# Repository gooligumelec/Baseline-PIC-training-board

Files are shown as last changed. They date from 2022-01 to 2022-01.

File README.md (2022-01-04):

# Gooligum Baseline PIC Training and Development Board

The Gooligum Baseline and Mid-Range PIC training board, previously available for sale from www.gooligum.com.au, was designed for use with the Gooligum PIC tutorials, which you can find at https://github.com/gooligumelec/PIC-tutorials.  It is also useful as a general development board for 6-, 8- and 14-pin baseline, midrange and enhanced midrange PICs.

The design files are being made available under the Creative Commons Attribution-ShareAlike 4.0 International license, which essentially means that they are free to use and share, provided that you attribute the original creator (me / Gooligum). See LICENSE.txt for details.

The files consist of the manual, Eagle schematic and board files, bill of materials in Excel format and a zip file containing the Gerber and drill CAM files.

Please note that I am not in a position to provide any support for this board.

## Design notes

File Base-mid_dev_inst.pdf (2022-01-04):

© Gooligum Electronics 2015 | www.gooligum.com.au
Baseline and mid-range PIC training and dev board operation guide | Page 1

## Baseline and Mid-Range PIC (6 – 14 pin)

## Training and Development Board

## Construction and Operation Guide

This PIC development board is designed as a training environment specifically for use with the introductory Gooligum baseline, mid-range and enhanced mid-range PIC tutorials¹

The tutorials were originally written for Microchip’s Low Pin Count Demo Board, which supports 8-, 14-and 20-pin PICs, can be used easily with a PICkit 2 or PICkit 3 programmer, and provides four LEDs, a pushbutton switch and a potentiometer. As such, it’s a good, simple introductory board. However, it does not support the 6-pin 10F PICs and its LEDs cannot be used directly with 8-pin PICs.

More significantly, many of the Gooligum baseline and mid-range lessons require the use of parts not included on that board, such as photocells, crystal-driven oscillator circuits, and 7-segment LED displays. Although it is possible to build all of these circuits on a breadboard, connected to the Low Pin Count Demo Board, it is a little cumbersome – especially for some of the more complex circuits.

This training board was developed to make it easy to follow the Gooligum baseline, mid-range and introductory enhanced mid-range lessons. It works with a PICkit 2 or PICkit 3 programmer, and supports all 8- and 14-pin baseline, mid-range and enhanced mid-range PICs, as well as all 6-pin 10F devices (in an 8-pin DIP package). It is fully configurable using the provided jumpers, and comes with all of the hardware needed for every introductory lesson, including all the required PICs.

It features:

- Support for all 6-pin, 8-pin and 14-pin baseline, mid-range and enhanced mid-range PICs (all 10F, 12F and 14-pin 16F devices)
- 2 × pushbuttons (including MCLR )
- optional external pull-up resistor on each pushbutton
- 9 × LEDs
- an LED is available on each 6-pin and 8-pin PIC output pin, plus pins RC0 – RC3
- 3 × 7-segment LED displays
- configurable as a single digit or multiplexed digits
- External 32.768 kHz oscillator
- can be configured to drive processor clock, Timer0 or Timer1
- 4 MHz resonator, 32.768 kHz crystal and resistor/capacitor for use with processor oscillator
- 32.768 kHz crystal also available for Timer1 oscillator
- Potentiometer and 2 × photocells for use as analog inputs in comparator and ADC lessons
- Variable frequency oscillator for frequency and pulse width measurement lessons
- Piezo sounder, to demonstrate PWM outputs
- Standard ICSP connector for use with PICkit 2 or PICkit 3 programmer

1 All baseline, mid-range, and introductory enhanced mid-range assembler and C lessons

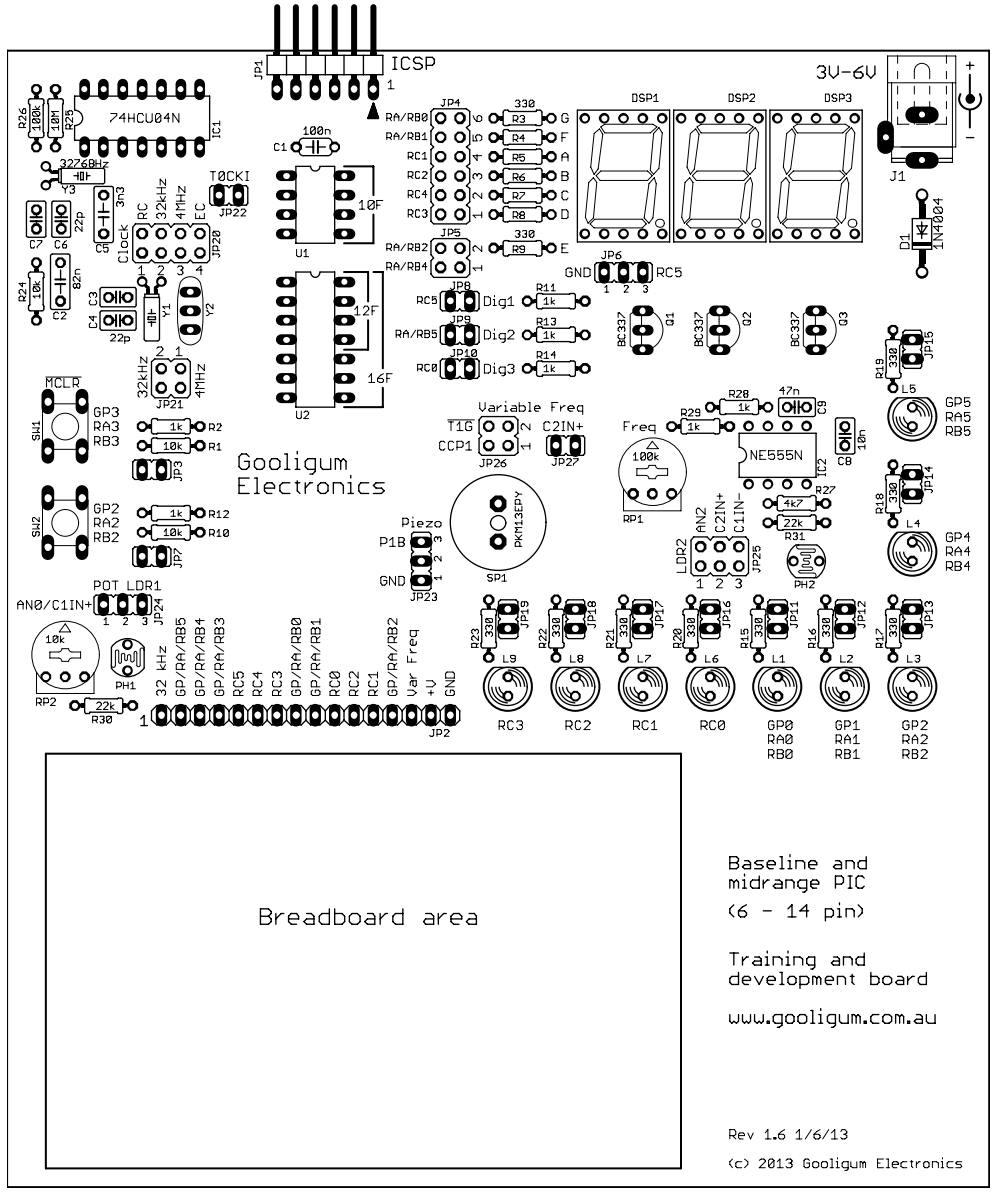
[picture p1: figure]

Baseline and mid-range PIC training and dev board operation guide | Page 2

Every PIC pin is brought out to the header at the bottom of the board, allowing the easy prototyping on the breadboard of circuits not covered by the onboard components, including circuits which require more than the 20 mA or so that a PICkit 2 or PICkit 3 can deliver, through the use of an external regulated DC power supply.

So, when you’ve completed all the lessons, you can continue to use the board for PIC development.

### Construction

[If your training board came fully assembled, you can ignore this section…]

The training board kit consists of a printed circuit board, a set of components to be soldered to the board, jumper shunts, rubber feet, a solderless breadboard, and solid hook-up wire (for use with the breadboard). It also comes with a bag of additional components for use with some of the Gooligum tutorial lessons – these are not to be mounted on the PCB. See the parts list, in appendix B, for details.

Construction is straight-forward, only needing basic soldering skills. All components are through-hole, and a component overlay (as shown below) is provided on the PCB.

Baseline and mid-range PIC training and dev board operation guide | Page 3

It is often easiest to build up a PCB by starting with the lowest-profile components, and working your way up in height – orienting them as shown in the overlay.

Be careful in particular with the orientation of the LEDs – although the anode lead is usually the longest, this is not always the case. It is safer to align the flat side of the case with the flat side of the overlay symbol (indicated the cathode).

The kit includes one green, one yellow and seven red LEDs. You can distribute these however you wish, but the colour scheme used in the prototype is green on GP0, yellow on GP1 and red on the rest.

The integrated circuits (74HCU04 and 555 timer) can be soldered directly to the PCB, in the positions marked IC1 and IC2 – taking care that the orientation is correct, with the notch on the IC (if any) aligned with the notch in the overlay symbol, and pin 1 (sometimes marked by a dot on the IC) immediately to the left of the notch. If you prefer to use IC sockets, that’s ok, but you will need to supply them yourself.

DO NOT use the supplied IC sockets for IC1 or IC2. These are to go in positions U1 and U2, to be used to mount the PICs that you will later use with this board.

Note that although the PCB overlay shows ‘BC337’, BC547 or BC548 transistors may have been supplied with your kit. That’s ok – they’ll all work fine in this application (driving the 7-segment displays) and have the same pin-out. Whichever type of transistor was supplied, you should orient them as shown on the overlay.

The 7-segment displays should be oriented with the decimal point in the lower right of each digit.

The jumper headers may have been supplied as a 32-pin single-row header, a 9-pin single-row header, and 19-position dual-row header. If so, they must be snapped (using pliers) into a number of smaller header blocks:

- 1 × 1×32-pin → 16 × 1×2-pin
- 1 × 1×9-pin → 3 × 1×3-pin
- 1 × 2×19-pin → 1 × 2×3-pin, 1 × 2×4-pin, 1 × 2×6-pin and 3 × 2×2-pin

Although the headers are a similar height to the LEDs, it is generally easiest to install them first, before installing the LEDs.

When you have soldered all the components to the PCB, peel the backing from the four rubber feet and attach them to the underside of the PCB, close to each corner.

You should also remove the paper backing from the solderless breadboard and attach it to the PCB, in the position shown in the overlay.

The supplied hook-up wire is used to make connections on the breadboard – you should put it aside and cut it into suitable lengths (with the insulation stripped from each end) as needed, later. Of course, if you already have a collection of breadboard jumper wires, feel free to use those instead!

The header shunts should also be put aside to use later, when you configure the training board for each lesson.

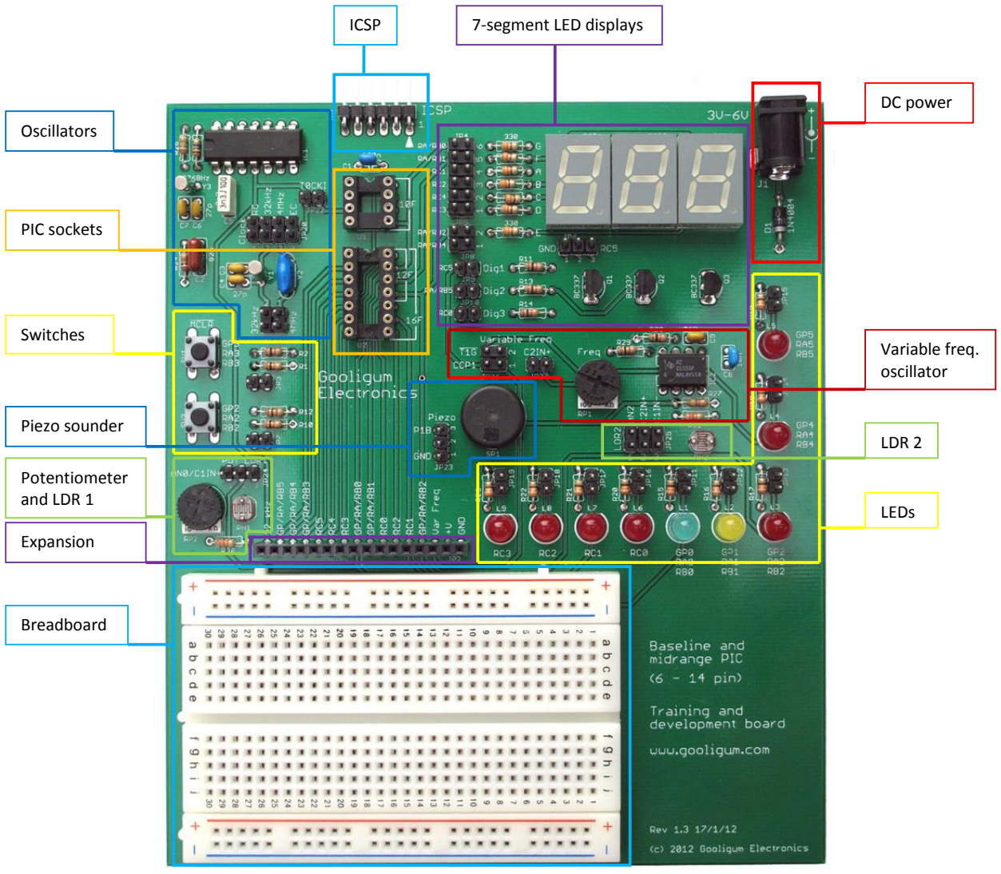
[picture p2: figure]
ICSP; Oscillators; Switches; Potentiometer and LDR 1; Breadboard; Expansion; Piezo sounder; 7-segment LED displays; DC power; PIC sockets; Variable freq. oscillator; LDR 2; LEDs

Baseline and mid-range PIC training and dev board operation guide | Page 4

### Operation

The training board consists of a number of functional blocks, as shown:

Plug your PIC microcontroller into one of the PIC sockets:
- Socket U1, marked ‘10F’, is for PIC10F devices²
- The upper section of socket U2, marked ‘12F’, is for 8-pin PIC12F devices
- The whole of socket U2, marked ‘16F’, is for 14-pin PIC16F devices

Note: you must plug a PIC into ONLY ONE socket at once. If you’ve been using a PIC10F and want to use a PIC12F or PIC16F, remove the PIC10F from the ‘10F’ socket first!

2 Although PIC10Fs are 6-pin devices, only those supplied in 8-pin DIP packages can be used (directly) with this training board. Only 6 pins of the 8-pin package are available for use; the PIC10F is still a 6-pin device.

Baseline and mid-range PIC training and dev board operation guide | Page 5

Plug your PICkit 2 or PICkit 3 programmer directly into the ICSP socket, with the arrow on the programmer aligned with the arrow on the PCB (indicating pin 1).

You would normally use the PICkit 2 or PICkit 3 to power the training board. These programmers can supply up to around 30 mA. If you need more current than this (up to 1 A), or if you wish to use the training board without having a PICkit 2 or PICkit 3 attached, you can connect a regulated power supply to the DC power socket.

This socket accepts a standard 5.5 mm barrel DC plug, with a 2.1 mm positive centre pin.

Note that there is no voltage regulator on the training board. A diode offers polarity protection, also dropping the supply voltage by at least 0.6 V. Since most baseline and mid-range PICs (including those used in the Gooligum tutorials) will work with a supply voltage of up to 5.5 V, you can safely use a power supply of up to 6 V to power most³
PICs with this training board – but it must be regulated!

A good choice for an external power supply is a 5 V regulated unit, which will supply around 4.3 V (after the diode voltage drop) to the PIC.

The LEDs are connected, via jumpers and 330 Ω resistors, to PIC pins as marked on the circuit board.

Various PICs use different names for the same pin. For example, pin 2 of socket U2 is referred to as GP5 if you plug a 12F509 into that socket, RA5 if you plug in a 16F684, and RB5 if you use a 16F506. For that reason, the LED connected to that pin is labelled ‘GP5 / RA5 / RB5’. On the other hand, pin 7 is called RC3 on all 14-pin PICs, so the LED on that pin is labelled simply ‘RC3’.

LEDs are available on all output pins except RC4 and RC5.

To enable (connect) an LED, simply close its associated jumper.

Pushbutton switches are connected to GP/RA/RB2 and GP/RA/RB3/ MCLR via 1 kΩ isolation resistors. They are active low: they will pull the input pin low when pressed (the isolation resistors ensure that the PIC won’t be damaged if a button is pressed while the pin connected to it is configured as a high output).

The inputs are normally held high, while the switch is open, by either an external 10 kΩ pull-up resistor, or an internal weak pull-up. Each external pull-up resistor is enabled by closing its associated jumper.

A 10 kΩ potentiometer and light-dependent resistor (LDR, or CDS photocell), forming one leg of a potential divider, are available as analog voltage sources. Either can be connected, via jumper JP24, to pin AN0 / CIN+ / C1IN+, to act as either an ADC or comparator input.

A second LDR can be connected, via jumper block JP25, to ADC input AN2 or comparator inputs C2IN+ or CIN- / C1IN-.

The board includes a 32.768 kHz oscillator, implemented with a watch crystal and CMOS inverter. Its buffered output can be used to drive Timer0 (in counter mode), by using JP22 to connect it to the T0CKI pin. It can also be used as an external signal to drive the processor clock, via jumper block JP20.

In a real PIC application, if you needed a 32.768 kHz clock, you’d be more likely to simply use a watch crystal with the PIC’s internal oscillator. The training board includes a second 32.768 kHz crystal (with load capacitors), which can be connected to OSC1 (on one side) via JP20 and to OSC2 (on the other

3
some PICs (mostly ‘LF’ variants) will only tolerate a supply of up to 3.6 V- you should limit your external power supply to no more than 4 V if you are using one of these devices

Baseline and mid-range PIC training and dev board operation guide | Page 6

side) via JP21. That is, to use the 32.768 kHz crystal with the PIC’s internal oscillator, you must connect it through both JP20 and JP21.

The same is true for the 4.00 MHz ceramic resonator. To use it with the PIC’s internal oscillator, connect one side of the resonator to OSC1 via JP20 and the other side to OSC2 via JP21.

A 10 kΩ resistor and 82 nF capacitor are also provided, and can be connected via JP20 to OSC1, to form an external RC oscillator with a frequency of around 1 kHz.

The 7-segment LED displays consist of three common-cathode digits, with the anodes of segments A-D, F and G connected via 330 Ω resistors and jumper block JP4 to pins RA/RB0-1 and RC1-4. Segment E can be connected via JP5 to either RA/RB2 or RA/RB4.

The common cathode of digit 1 (the digit on the left) can be connected either to ground or a transistor controlled by RC5, using jumper JP6.

The cathodes of digits 2 and 3 are connected to transistors controlled by RA/RB5 and RC0 respectively.

The base of each of these NPN transistors is connected to its associated PIC pin through a 1 kΩ resistor and a jumper: JP8 for digit 1, JP9 for digit 2, and JP10 for digit 3. When the PIC pin pulls the base high, the transistor conducts, shorting the common cathode of the attached digit to ground.

So, to use just a single digit:

- Connect segments A-D, F and G to their associated PIC pins, by placing a shunt across every position in jumper block JP4. That is, you use six shunts at once, in JP4.
- Connect segment E to either RA/RB2 or RA/RB4, by placing a shunt in one of the two positions in jumper block JP5, selecting the PIC pin to be used for segment E.
- Connect the common cathode of digit 1 to ground, by placing a shunt across pins 1 and 2 of jumper JP6.
- Leave jumpers JP8, JP9 and JP10 open, so that the transistors will not conduct.

To use multiple digits:

- Connect segments A-G to PIC pins using jumper blocks JP4 and JP5, as above.
- If you want to use digit 1, connect its common cathode to the transistor controlled by RC5, by placing a shunt across pins 2 and 3 of JP6.
- Connect the transistors controlling whichever digits you wish to use to their associated PIC pins, using jumpers JP8, JP9 and JP10

For a two-digit display, you would normally use digits 1 and 2, by connecting pins 2 and 3 of JP6, closing JP8 and JP9, and leaving JP10 open. The two digits would be activated by RC5 and RA/RB5.

But you could instead choose to use digits 2 and 3, by closing JP9 and JP10, and leaving JP6 and JP8 open. The two digits would then be activated by RA/RB5 and RC0.

For a three-digit display, connect pins 2 and 3 of JP6, and close JP8, JP9 and JP10. The three digits are activated by RC5, RA/RB5 and RC0.

Note that, if you are using multiple digits, you should ensure that only one transistor (and hence digit) is activated at once.

The variable frequency oscillator, based on a 555 timer, provides a signal with a frequency that can be varied from approximately 150 Hz to 10 kHz, using trimpot RP1.

The digital form of this signal can be connected to either the Timer 1 gate input, T1G , or the capture input pin, CCP1, using jumper block JP26.

Baseline and mid-range PIC training and dev board operation guide | Page 7

A sawtooth form of the variable frequency signal can be connected to comparator input C2IN+, via jumper JP27.

A piezo sounder is connected directly to pin RC5, which is also PWM output P1A.

To drive the piezo using a single-ended PWM output (or by toggling RC5), the other side of the piezo should be connected to ground, by placing a shunt across positions 1 and 2 of jumper JP23.

Alternatively, the piezo can be driven (at higher volume) by a double-ended or half-bridge PWM output, by placing a shunt across positions 2 and 3 of JP23, connecting its other side to PWM output P1B.

Finally, every PIC pin, the 32.768 kHz and variable frequency signals and the power supply are brought out to a 16-pin expansion header, next to the breadboard (making it easy to build custom circuits and to use this training board a general 6 – 14-pin PIC development board), as follows:

Pin | Description
1 | 32.768 kHz buffered digital signal
2 | GP5 / RA5 / RB5
3 | GP4 / RA4 / RB4
4 | GP3 / RA3 / RB3
5 | RC5
6 | RC4
7 | RC3
8 | GP0 / RA0 / RB0
9 | GP1 / RA1 / RB1
10 | RC0
11 | RC2
12 | RC1
13 | GP2 / RA2 / RB2
14 | Variable frequency (150 – 10000 Hz) digital signal
15 | Power (+V)
16 | Ground

Baseline and mid-range PIC training and dev board operation guide | Page 8

Jumper summary

As described above, jumpers are used to configure each function, bringing different elements in or out of the circuit. Although the function of each jumper is annotated on the PCB overlay, here is a summary of what each jumper is used for:

Jumper | Position | Function
JP3 | - | Enables external pull-up resistor on GP3 / RA3 / RB3 / MCLR
JP4 | 1 | Connects RC3 to LED digits segment D
| 2 | Connects RC4 to LED digits segment C
| 3 | Connects RC2 to LED digits segment B
| 4 | Connects RC1 to LED digits segment A
| 5 | Connects RA1 / RB1 to LED digits segment F
| 6 | Connects RA0 / RB0 to LED digits segment G
JP5 | 1 | Connects RA4 / RB4 to LED digits segment E
| 2 | Connects RA2 / RB2 to LED digits segment E
JP6 | 1-2 | Connects common cathode of LED digit 1 to ground
| 2-3 | Connects common cathode of LED digit 1 to transistor controlled by RC5
JP7 | - | Enables external pull-up resistor on GP2 / RA2 / RB2
JP8 | - | Connects RC5 to transistor on LED digit 1
JP9 | - | Connects RA5 / RB5 to transistor on LED digit 2
JP10 | - | Connects RC0 to transistor on LED digit 1
JP11 | | Connects GP0 / RA0 / RB0 to LED L1
JP12 | | Connects GP1 / RA1 / RB1 to LED L2
JP13 | | Connects GP2 / RA2 / RB2 to LED L3
JP14 | | Connects GP4 / RA4 / RB4 to LED L4
JP15 | | Connects GP5 / RA5 / RB5 to LED L5
JP16 | | Connects RC0 to LED L6
JP17 | | Connects RC1 to LED L7
JP18 | | Connects RC2 to LED L8
JP19 | | Connects RC3 to LED L9
JP20 | 1 | Connects OSC1 to 10 kΩ resistor and 82 nF capacitor (RC oscillator)
| 2 | Connects OSC1 to 32.768 kHz watch crystal (LP oscillator)
| 3 | Connects OSC1 to 4.00 MHz ceramic resonator (XT oscillator)
| 4 | Connects OSC1 to 32.768 kHz external clock (EC mode)
JP21 | 1 | Connects OSC2 to 4.00 MHz ceramic resonator (XT oscillator)
| 2 | Connects OSC2 to 32.768 kHz watch crystal (LP oscillator)

Baseline and mid-range PIC training and dev board operation guide | Page 9
JP22 | - | Connects T0CKI to 32.768 kHz external clock
JP23 | 1-2 | Connects one side of piezo sounder to ground (other side connects to P1A)
| 2-3 | Connects one side of piezo sounder to P1B (other side connects to P1A)
JP24 | 1-2 | Connects 10 kΩ potentiometer to RA0 / CIN+ / C1IN+
| 2-3 | Connects LDR1 to AN0 / CIN+ / C1IN+
JP25 | 1 | Connects LDR2 to AN2
| 2 | Connects LDR2 to C2IN+
| 3 | Connects LDR2 to CIN- / C1IN-
JP26 | 1 | Connects digital variable frequency signal to CCP1
| 2 | Connects digital variable frequency signal to T1G
JP27 | - | Connects sawtooth variable frequency signal to C2IN+

Baseline and mid-range PIC training and dev board operation guide | Page 10

### Appendix A – Jumper settings

The tables on the following pages show how the jumpers on the training board should be configured, for each baseline, mid-range or introductory enhanced mid-range tutorial example.

Use a shunt to connect jumpers indicated by ‘●’.

A single digit indicates that you should place a shunt at that numbered position in a jumper block.

‘1-2’ and ‘2-3’ mean that a shunt should be used to connect positions 1 and 2, or 2 and 3, of that jumper.

Jumper block JP4, used to connect PIC pins to six of the 7-segment display anodes, is all or nothing. Where you see ‘all’, you should place shunts across all six jumpers, numbered 1-6, in the block.

Where a table cell is blank, the jumper should be left open.

In many cases, it won’t matter if additional jumpers are connected, but to ensure that the board is correctly configured for each lesson, you should leave each jumper unconnected, unless specified.

For example, for mid-range assembler lesson 15, example 6, install shunts on:

- JP3 (enabling the pull-up resistor on the pushbutton on RA3)
- all positions (1-6) of JP4. connecting pins RA0-1 and RC1-4 to segments A-D and F-G of the 7-segment displays
- position 2 of JP5, connecting pin RA2 to segment E of the 7-segment displays
- pins 1 and 2 of JP6, connecting the common cathode of digit 1 to ground
- position 2 of JP20, connecting one side of a 32.768 kHz watch crystal to OSC1
- position 2 of JP21, connecting the other side of the watch crystal to OSC2

Every other jumper should remain open.

Baseline and mid-range PIC training and dev board operation guide | Page 11
Table A-1: Baseline assembler GP/RA³ pull-up | segment A⁻D,F,G | segment E | digit 1 cathode

GP/RA2 pull-up
RC5 → digit 1

RA5 → digit 2
RC0 → digit 3
GP/RA0 LED

GP/RA1 LED

GP/RA2 LED

GP/RA4 LED

GP/RA5 LED
RC0 LED

RC1 LED

RC2 LED

RC3 LED

Clock source

Crystal

32 kHz → T0CKI

Piezo

AN0 source

LDR2

Var Freq (digital)

Var Freq (analog)

Lesson | Example | 3 | 4 | 5 | 6 | 7 | 8 | 9 | 10 | 11 | 12 | 13 | 14 | 15 | 16 | 17 | 18 | 19 | 20 | 21 | 22 | 23 | 24 | 25 | 26 | 27
1 | 1 | | | | | | | | | | ●
2 | 1 | | | | | | | | | | ●
3 | 1 | | | | | | | | | | ●
| 2 | | | | | | | | | | ●
| 3 | | | | | | | | | | ●
4 | 1 | ● | | | | | | | | | ●
| 2 | ● | | | | | | | | | ●
| 3 | | | | | | | | | | ●
5 | 1 | ● | | | | | | | | | ● | ●
| 2 | ● | | | | | | | | | ● | ●
| 3 | ● | | | | | | | | | ●
| 4 | | | | | | | | | | ● | | | | | | | | | | ●
6 | 1 | | | | | | | | | | ●
| 2 | ● | | | | | | | | | ● | ●
| 3 | | | | | | | | | | ● | | | | | | | | | | ●
| 4 | ● | | | | | | | | | ●
| 5 | ● | | | | ● | | | | ● | ●
| 6 | | | | | | | | | | ●
7 | 1 | ● | | | | | | | | | ●
| 2 | ● | | | | | | | | | ● | ●
| 3 | | | | | | | | | | ● | ●
| 4a | | | | | | | | | | ● | | | | | | | | 4
| 4b | | | | | | | | | | ● | | | | | | | | 2 | 2
| 4c | | | | | | | | | | ● | | | | | | | | 3 | 1
| 4d | | | | | | | | | | ● | | | | | | | | 1
8 | 1 | | all | 1 | 1-2
| 2 | | all | 1 | 2-3 | | ● | ● | ●
| 3 | | all | 1 | 2-3 | | ● | ● | ●
9 | 1a | | | | | | | | | | | | | | | | | ● | | | | | 1-2
| 1b | | | | | | | | | | | | | | | | | ● | | | | | 2-3
| 1c | | | | | | | | | | | | | | | | | ● | | | | | 2-3
| 1d | | | | | | | | | | | | | | | | | ● | | | | | 2-3
| 2 | | | | | | | | | | | | | | | | | ● | | | | | 2-3
| 3 | | | | | | | | | | | | | | | | | ●
| 4 | | | | | | | | | | | | | | | ● | | ● | | | | | | 2
| 5 | | | | | | | | | | | | | | | ● | | ● | | | | | 2-3 | 2
10 | 1 | | | | | | | | | | | | | | ● | ● | ● | ● | | | | | 1-2
| 2 | | all | 1 | 2-3 | | ● | ● | | | | | | | | | | | | | | | | 1
| 3 | | all | 1 | 2-3 | | ● | ● | | | | | | | ●
11 | 1 | | all | 1 | 2-3 | | ● | ● | | | | | | | | | | | | | | | | 1
| 2 | | all | 1 | 2-3 | | ● | ● | | | | | | | | | | | | | | | | 1

Baseline and mid-range PIC training and dev board operation guide | Page 12

Table A-2: Baseline C

GP/RA3 pull-up

segment A-D,F,G

segment E

digit 1 cathode

GP/RA2 pull-up
RC5 → digit 1

RA5 → digit 2
RC0 → digit 3
GP/RA0 LED

GP/RA1 LED

GP/RA2 LED

GP/RA4 LED

GP/RA5 LED
RC0 LED

RC1 LED

RC2 LED

RC3 LED

Clock source

Crystal

32 kHz → T0CKI

Piezo

AN0 source

LDR2

Var Freq (digital)

Var Freq (analog)

Lesson | Example | 3 | 4 | 5 | 6 | 7 | 8 | 9 | 10 | 11 | 12 | 13 | 14 | 15 | 16 | 17 | 18 | 19 | 20 | 21 | 22 | 23 | 24 | 25 | 26 | 27
1 | 1 | | | | | | | | | | ●
| 2 | | | | | | | | | | ●
| 3 | | | | | | | | | | ●
2 | 1 | ● | | | | | | | | | ●
| 2 | ● | | | | | | | | | ●
| 3 | | | | | | | | | | ●
3 | 1 | ● | | | | | | | | | ● | ●
| 2 | ● | | | | | | | | | ● | ●
| 3 | ● | | | | | | | | | ●
| 4 | | | | | | | | | | ● | | | | | | | | | | ●
4 | 1 | ● | | | | | | | | | ●
| 2 | ● | | | | | | | | | ● | ●
| 3 | | | | | | | | | | ● | ●
5 | 1 | | all | 1 | 1-2
| 2 | | all | 1 | 2-3 | | ● | ● | ●
6 | 1a | | | | | | | | | | | | | | | | | ● | | | | | 1-2
| 1b | | | | | | | | | | | | | | | | | ● | | | | | 2-3
| 1c | | | | | | | | | | | | | | | | | ● | | | | | 2-3
| 1d | | | | | | | | | | | | | | | | | ● | | | | | 2-3
| 2 | | | | | | | | | | | | | | | | | ● | | | | | 2-3
| 3 | | | | | | | | | | | | | | | | | ●
| 4 | | | | | | | | | | | | | | | ● | | ● | | | | | | 2
| 5 | | | | | | | | | | | | | | | ● | | ● | | | | | 2-3 | 2
7 | 1 | | | | | | | | | | | | | | ● | ● | ● | ● | | | | | 1-2
| 2 | | all | 1 | 2-3 | | ● | ● | | | | | | | | | | | | | | | | 1
| 3 | | all | 1 | 2-3 | | ● | ● | | | | | | | ●
| 4 | | all | 1 | 2-3 | | ● | ● | | | | | | | | | | | | | | | | 1
| 5 | | all | 1 | 2-3 | | ● | ● | | | | | | | | | | | | | | | | 1

Baseline and mid-range PIC training and dev board operation guide | Page 13
Table A-3a: Mid-range assembler (lessons 1 - 8) GP/RA³ pull-up | segment A⁻D,F,G | segment E | digit 1 cathode | GP/RA² pull-up | RC5 → digit 1 | RA⁵ → digit 2 | RC0 → digit 3 | GP/RA⁰ LED | GP/RA¹ LED

GP/RA2 LED

GP/RA4 LED

GP/RA5 LED
RC0 LED

RC1 LED

RC2 LED

RC3 LED

Clock source

Crystal

32 kHz → T0CKI

Piezo

AN0 source

LDR2

Var Freq (digital)

Var Freq (analog)

Lesson | Example | 3 | 4 | 5 | 6 | 7 | 8 | 9 | 10 | 11 | 12 | 13 | 14 | 15 | 16 | 17 | 18 | 19 | 20 | 21 | 22 | 23 | 24 | 25 | 26 | 27
1 | 1 | ● | | | | | | | | | ●
| 2 | ● | | | | | | | | | ●
2 | 1 | ● | | | | | | | | | ●
| 2 | ● | | | | | | | | | ●
| 3 | ● | | | | | | | | | ●
3 | 1 | ● | | | | | | | | | ●
| 2 | ● | | | | | | | | | ●
| 3 | | | | | | | | | | ●
4 | 1 | ● | | | | | | | | | ● | ●
| 2 | ● | | | | | | | | | ● | ●
| 3 | ● | | | | | | | | | ●
| 4 | ● | | | | | | | | | ● | | | | | | | | | | ●
5 | 1 | ● | | | | | | | | | ●
| 2 | ● | | | | | | | | | ● | ●
| 3 | ● | | | | | | | | | ● | | | | | | | | | | ●
| 4 | ● | | | | | | | | | ●
| 5 | ● | | | | ● | | | | ● | ●
| 6 | ● | | | | | | | | | ●
6 | 1 | ● | | | | | | | | | | ●
| 2 | ● | | | | | | | | | ● | ●
| 3 | ● | | | | | | | | | ●
| 4 | ● | | | | | | | | | ● | ●
| 5 | ● | | | | ● | | | | | ●
| 6 | ● | | | | ● | | | | ● | ●
7 | 1 | ● | | | | ● | | | | | ●
| 2 | ● | | | | ● | | | | ● | ●
| 3 | ● | | | | | | | | | ●
| 4 | ● | | | | | | | | | ●
| 5 | ● | | | | | | | | | ● | ●
| 6 | ● | | | | | | | | | ●
8 | 1 | ●
| 2 | ● | | | | | | | | | ● | | | | | | | | 4
| 3 | ● | | | | | | | | | ● | | | | | | | | 2 | 2
| 4 | ● | | | | | | | | | ● | | | | | | | | 3 | 1
| 5 | ● | | | | | | | | | ● | | | | | | | | 1
| 6 | ● | | | | | | | | ● | ● | ●

Baseline and mid-range PIC training and dev board operation guide | Page 14
Table A-3b: Mid-range assembler (lessons 9 - 17) GP/RA³ pull-up | segment A⁻D,F,G | segment E | digit 1 cathode | GP/RA² pull-up | RC5 → digit 1 | RA⁵ → digit 2 | RC0 → digit 3

GP/RA0 LED

GP/RA1 LED

GP/RA2 LED

GP/RA4 LED

GP/RA5 LED
RC0 LED

RC1 LED

RC2 LED

RC3 LED

Clock source

Crystal

32 kHz → T0CKI

Piezo

AN0 source

LDR2

Var Freq (digital)

Var Freq (analog)

Lesson | Example | 3 | 4 | 5 | 6 | 7 | 8 | 9 | 10 | 11 | 12 | 13 | 14 | 15 | 16 | 17 | 18 | 19 | 20 | 21 | 22 | 23 | 24 | 25 | 26 | 27
9 | 1a | ● | | | | | | | | | | | | ● | | | | | | | | | 1-2
| 1b | ● | | | | | | | | | | | | ● | | | | | | | | | 2-3
| 2 | ● | | | | | | | | | | | | ● | | | | | | | | | 2-3
| 3 | ● | | | | | | | | | | | | ● | | | | | | | | | 2-3
| 4 | ● | | | | | | | | | | | | ● | | | | | | | | | 2-3
| 5 | ● | | | | | | | | | | | | ● | | | | | | | | | 2-3
| 6 | ● | | | | | | | | | | | ● | ● | | | | | | | | | 2-3
| 7 | ● | | | | | | | | | | | ● | ● | | | | | | | | | 2-3 | 3
10 | 1 | | | | | | | | | | | | | | ● | ● | ● | ●
| 2 | | | | | | | | | | | | | | ●
| 3 | | | | | | | | | | | | | | ●
11 | 1 | | | | | | | | | | | | ● | ● | | | ● | ● | | | | | 2-3 | 3
| 2 | | | | | | | | | | | | | | | | ● | ● | | | | | | 3
| 3 | | | | | | | | | | | | | | | | ● | ● | | | | | | 2
12 | 1 | | all | 1 | 1-2
| 2 | | all | 1 | 2-3 | | ● | ● | ●
| 3 | | all | 1 | 2-3 | | ● | ● | ●
13 | 1 | | | | | | | | | | | | | | ● | ● | ● | ● | | | | | 1-2
| 2 | | | | | | | | | | | | | | ● | ● | ● | ● | | | | | 1-2
| 3 | | all | 1 | 2-3 | | ● | ● | ● | | | | | | | | | | | | | | | 1
| 4 | | all | 1 | 2-3 | | ● | ● | ● | | | | | | | | | | | | | | | 1
| 5 | | all | 1 | 2-3 | | ● | ● | | | | | | | ●
14 | 1 | | all | 1 | 2-3 | | ● | ● | | | | | | | | | | | | | | | | 1
| 2 | | all | 1 | 2-3 | | ● | ● | | | | | | | | | | | | | | | | 1
15 | 1 | ● | | | | | | | | | | | | | ● | ●
| 2 | ● | | | | | | | | | | | | | ● | ●
| 3 | | | | | | | | | | | | | | ● | | | | 4
| 4 | | | | | | | | | | | | | | ● | | | | 2 | 2
| 5 | | all | 2 | 1-2 | | | | | | | | | | | | | | 2 | 2
| 6 | ● | all | 2 | 1-2 | | | | | | | | | | | | | | 2 | 2
| 7 | | all | 2 | 1-2 | | | | | | | | | | | | | | | | | | | | 2
| 8 | | all | 2 | 1-2 | | | | | | | | | | | | | | | | | | | | | ●
16 | 1 | | | | | | | | | | | | | | ●
17 | 1 | | all | 2 | 1-2 | | | | | | | | | | | | | | | | | | | | 1
| 2 | | all | 2 | 1-2 | | | | | | | | | | | | | | | | | | | | 1
| 3 | | all | 2 | 1-2 | | | | | | | | | | | | | | | | | | | | 1
| 4 | | | | | | | | | | | | | | | | | ●
| 5 | | | | | | | | | | | | | | | | | ●
| 6 | | | | | | | | | | | | | | | | | ●
| 7 | | all | 1 | 2-3 | | ● | ● | | | | | | | | | | | | | | | | 1

Baseline and mid-range PIC training and dev board operation guide | Page 15
Table A-3c: Mid-range assembler (lessons 18 - 19) GP/RA³ pull-up | segment A⁻D,F,G | segment E | digit 1 cathode | GP/RA² pull-up | RC5 → digit 1 | RA⁵ → digit 2 | RC0 → digit 3 | GP/RA⁰ LED | GP/RA¹ LED

GP/RA2 LED

GP/RA4 LED

GP/RA5 LED
RC0 LED

RC1 LED

RC2 LED

RC3 LED

Clock source

Crystal

32 kHz → T0CKI

Piezo

AN0 source

LDR2

Var Freq (digital)

Var Freq (analog)

Lesson | Example | 3 | 4 | 5 | 6 | 7 | 8 | 9 | 10 | 11 | 12 | 13 | 14 | 15 | 16 | 17 | 18 | 19 | 20 | 21 | 22 | 23 | 24 | 25 | 26 | 27
18 | 1
| 2 | | | | | | | | | | | | | | | | | | | | | 1-2 | 1-2
| 3 | | | | | | | | | | | | | | | | | ● | | | | | 1-2
| 4 | | | | | | | | | | | | | | | | | | | | | | 1-2
| 5 | | | | | | | | | | | | | | | | | | | | | 2-3
| 6 | | | | | | | | | | | | | | | | | | | | | | 1-2
| 7 | | | | | | | | | | | | | | | | | | | | | | 1-2
| 8 | | | | | | | | | | | | | | | | | | | | | | 1-2
19 | 1 | | all | 1 | 2-3 | | ● | ● | ●
| 2 | | all | 1 | 2-3 | | ● | ● | ●

Baseline and mid-range PIC training and dev board operation guide | Page 16
Table A-4a: Mid-range C (lessons 1 - 6) GP/RA³ pull-up | segment A⁻D,F,G | segment E | digit 1 cathode | GP/RA² pull-up | RC5 → digit 1 | RA⁵ → digit 2

RC0 → digit 3
GP/RA0 LED

GP/RA1 LED

GP/RA2 LED

GP/RA4 LED

GP/RA5 LED
RC0 LED

RC1 LED

RC2 LED

RC3 LED

Clock source

Crystal

32 kHz → T0CKI

Piezo

AN0 source

LDR2

Var Freq (digital)

Var Freq (analog)

Lesson | Example | 3 | 4 | 5 | 6 | 7 | 8 | 9 | 10 | 11 | 12 | 13 | 14 | 15 | 16 | 17 | 18 | 19 | 20 | 21 | 22 | 23 | 24 | 25 | 26 | 27
1 | 1 | ● | | | | | | | | | ●
| 2 | ● | | | | | | | | | ●
| 3 | ● | | | | | | | | | ●
| 4 | ● | | | | | | | | | ●
| 5 | ● | | | | | | | | | ●
| 6 | | | | | | | | | | ●
2 | 1 | ● | | | | | | | | | ● | ●
| 2 | ● | | | | | | | | | ● | ●
| 3 | ● | | | | | | | | | ●
| 4 | ● | | | | | | | | | ● | | | | | | | | | | ●
3 | 1 | ● | | | | | | | | | | ●
| 2 | ● | | | | | | | | | ● | ●
| 3 | ● | | | | | | | | | ●
| 4 | ● | | | | | | | | | ● | ●
| 5 | ● | | | | ● | | | | | ●
| 6 | ● | | | | ● | | | | ● | ●
4 | 1 | ● | | | | ● | | | | | ●
| 2 | ● | | | | ● | | | | ● | ●
| 3 | ● | | | | | | | | | ●
| 4 | ● | | | | | | | | | ●
| 5 | ● | | | | | | | | | ● | ●
| 6 | ● | | | | | | | | | ●
5 | 1 | ●
| 2 | ● | | | | | | | | | ● | | | | | | | | 4
| 3 | ● | | | | | | | | | ● | | | | | | | | 2 | 2
| 4 | ● | | | | | | | | | ● | | | | | | | | 3 | 1
| 5 | ● | | | | | | | | | ● | | | | | | | | 1
| 6 | ● | | | | | | | | ● | ● | ●
6 | 1 | ● | | | | | | | | | | | | ● | | | | | | | | | 2-3
| 2 | ● | | | | | | | | | | | | ● | | | | | | | | | 2-3
| 3 | ● | | | | | | | | | | | | ● | | | | | | | | | 2-3
| 4 | ● | | | | | | | | | | | | ● | | | | | | | | | 2-3
| 5 | ● | | | | | | | | | | | | ● | | | | | | | | | 2-3
| 6 | ● | | | | | | | | | | | ● | ● | | | | | | | | | 2-3
| 7 | ● | | | | | | | | | | | ● | ● | | | | | | | | | 2-3 | 3
| 8 | | | | | | | | | | | | ● | ● | | | ● | ● | | | | | 2-3 | 3
| 9 | | | | | | | | | | | | | | | | ● | ● | | | | | | 3
| 10 | | | | | | | | | | | | | | | | ● | ● | | | | | | 2

Baseline and mid-range PIC training and dev board operation guide | Page 17
Table A-4b: Mid-range C (lessons 7 - 13) GP/RA³ pull-up | segment A⁻D,F,G | segment E | digit 1 cathode | GP/RA² pull-up | RC5 → digit 1 | RA⁵ → digit 2 | RC0 → digit 3

GP/RA0 LED

GP/RA1 LED

GP/RA2 LED

GP/RA4 LED
GP/RA5 LED
RC0 LED

RC1 LED

RC2 LED

RC3 LED

Clock source

Crystal

32 kHz → T0CKI

Piezo

AN0 source

LDR2

Var Freq (digital)

Var Freq (analog)

Lesson | Example | 3 | 4 | 5 | 6 | 7 | 8 | 9 | 10 | 11 | 12 | 13 | 14 | 15 | 16 | 17 | 18 | 19 | 20 | 21 | 22 | 23 | 24 | 25 | 26 | 27
7 | 1 | | all | 1 | 1-2
| 2 | | all | 1 | 2-3 | | ● | ● | ●
8 | 1 | | | | | | | | | | | | | | ● | ● | ● | ● | | | | | 1-2
| 2 | | | | | | | | | | | | | | ● | ● | ● | ● | | | | | 1-2
| 3 | | all | 1 | 2-3 | | ● | ● | ● | | | | | | | | | | | | | | | 1
| 4 | | all | 1 | 2-3 | | ● | ● | ● | | | | | | | | | | | | | | | 1
| 5 | | all | 1 | 2-3 | | ● | ● | | | | | | | ●
| 6 | | all | 1 | 2-3 | | ● | ● | | | | | | | | | | | | | | | | 1
| 7 | | all | 1 | 2-3 | | ● | ● | | | | | | | | | | | | | | | | 1
9 | 1 | ● | | | | | | | | | | | | | ● | ●
| 2 | ● | | | | | | | | | | | | | ● | ●
| 3 | | | | | | | | | | | | | | ● | | | | 2 | 2
| 4 | | all | 2 | 1-2 | | | | | | | | | | | | | | 2 | 2
| 5 | ● | all | 2 | 1-2 | | | | | | | | | | | | | | 2 | 2
| 6 | | all | 2 | 1-2 | | | | | | | | | | | | | | | | | | | | 2
| 7 | | all | 2 | 1-2 | | | | | | | | | | | | | | | | | | | | | ●
10 | 1 | | | | | | | | | | | | | | ●
11 | 1 | | all | 2 | 1-2 | | | | | | | | | | | | | | | | | | | | 1
| 2 | | all | 2 | 1-2 | | | | | | | | | | | | | | | | | | | | 1
| 3 | | all | 2 | 1-2 | | | | | | | | | | | | | | | | | | | | 1
| 4 | | | | | | | | | | | | | | | | | ●
| 5 | | | | | | | | | | | | | | | | | ●
| 6 | | | | | | | | | | | | | | | | | ●
| 7 | | all | 1 | 2-3 | | ● | ● | | | | | | | | | | | | | | | | 1
12 | 1
| 2 | | | | | | | | | | | | | | | | | | | | | 1-2 | 1-2
| 3 | | | | | | | | | | | | | | | | | ● | | | | | 1-2
| 4 | | | | | | | | | | | | | | | | | | | | | | 1-2
| 5 | | | | | | | | | | | | | | | | | | | | | 2-3
| 6 | | | | | | | | | | | | | | | | | | | | | | 1-2
| 7 | | | | | | | | | | | | | | | | | | | | | | 1-2
| 8 | | | | | | | | | | | | | | | | | | | | | | 1-2
13 | 1 | | all | 1 | 2-3 | | ● | ● | ●
| 2 | | all | 1 | 2-3 | | ● | ● | ●
| 3 | | all | 1 | 2-3 | | ● | ● | ●

Baseline and mid-range PIC training and dev board operation guide | Page 18
Table A-5: Migrating to enhanced mid-range assembler GP/RA³ pull-up | segment A⁻D,F,G | segment E | digit 1 cathode | GP/RA² pull-up | RC5 → digit 1 | RA⁵ → digit 2 | RC0 → digit 3 | GP/RA⁰ LED | GP/RA¹ LED | GP/RA² LED | GP/RA⁴ LED

GP/RA5 LED
RC0 LED

RC1 LED

RC2 LED

RC3 LED

Clock source

Crystal

32 kHz → T0CKI

Piezo

AN0 source

LDR2

Var Freq (digital)

Var Freq (analog)

Lesson | Example | 3 | 4 | 5 | 6 | 7 | 8 | 9 | 10 | 11 | 12 | 13 | 14 | 15 | 16 | 17 | 18 | 19 | 20 | 21 | 22 | 23 | 24 | 25 | 26 | 27
1 | 1 | ● | | | | | | | | | ●
| 2 | ● | | | | | | | | | ●
| 3 | ● | | | | | | | | | ●
| 4 | ● | | | | | | | | | ●
| 5 | ● | | | | | | | | | ●
| 6 | | | | | | | | | | ●
2 | 1 | ● | | | | | | | | ● | ●
| 2 | | | | | | | | | | ● | | | | | | | | | | ●
| 3 | ● | | | | | | | | ● | ●
| 4 | | | | | ● | | | | | ●
3 | 1 | | | | | ● | | | | | ●
| 2 | | | | | ● | | | | ● | ●
| 3 | ● | | | | | | | | | ●
| 4 | ● | | | | | | | | | ●
| 5 | | | | | | | | | ● | ●
| 6 | | | | | | | | | | ●
4 | 1 | ● | | | | | | | | | | | | | | | ●
| 2 | | | | | | | | | | | | | | | | ● | | 3 | 1
| 3 | | | | | | | | | | | | | | | | ● | | 1
| 4 | | | | | | | | | | | | ● | | | | | | 1
| 5 | ● | | | | | | | | ● | ● | ●
5 | 1a | | | | | | | | | | | ● | | | | | | | | | | | 1-2
| 1b | | | | | | | | | | | ● | | | | | | | | | | | 1-2
| 1c | | | | | | | | | | | ● | | | | | | | | | | | 2-3
| 1d | | | | | | | | | | | ● | | | | | | | | | | | 2-3
| 2 | | | | | | | | | | | | | | | ● | | | | | | | | 3
| 3 | | | | | | | | | | | | | | | ● | | | | | | | | 3
| 4 | | | | | | | | | | | | | | | ● | | | | | | | | 3
| 5 | | | | | | | | | | | | | | | ● | | | | | | | | 3
| 6
| 7 | | | | | | | | | | | | | | | ● | | ● | | | | | | 3
6 | 1 | | all | 1 | 1-2
7 | 1 | | | | | | | | | | | | | | ● | ● | ● | ● | | | | | 1-2
| 2 | | all | 1 | 2-3 | | ● | ● | | | | ●
8 | 1 | | all | 1 | 2-3 | | ● | ● | | | | | | | | | | | | | | | | 1
| 2 | | all | 1 | 2-3 | | ● | ● | | | | | | | | | | | | | | | | 1
9 | 1 | | all | 2 | 1-2 | | | | | | | | | | | | | | | | | | | | 2
| 2 | | all | 2 | 1-2 | | | | | | | | | | | | | | | | | | | | 2
| 3 | | all | 2 | 1-2
10 | 1 | | | | | | | | | | | | | | ●
11 | 1 | | | | | | | | | | | | | | | | | ●
| 2 | | | | | | | | | | | | | | | ● | | | | | | | 1-2
| 3 | | | | | | | | | | | | | | | | | | | | | 2-3

Baseline and mid-range PIC training and dev board operation guide | Page 19
Table A-6: Migrating to enhanced mid-range C GP/RA³ pull-up | segment A⁻D,F,G | segment E | digit 1 cathode | GP/RA² pull-up | RC5 → digit 1 | RA⁵ → digit 2 | RC0 → digit 3 | GP/RA⁰ LED

GP/RA1 LED

GP/RA2 LED

GP/RA4 LED

GP/RA5 LED
RC0 LED

RC1 LED

RC2 LED

RC3 LED

Clock source

Crystal

32 kHz → T0CKI

Piezo

AN0 source

LDR2

Var Freq (digital)

Var Freq (analog)

Lesson | Example | 3 | 4 | 5 | 6 | 7 | 8 | 9 | 10 | 11 | 12 | 13 | 14 | 15 | 16 | 17 | 18 | 19 | 20 | 21 | 22 | 23 | 24 | 25 | 26 | 27
1 | 1 | ● | | | | | | | | | ●
| 2 | ● | | | | | | | | | ●
| 3 | ● | | | | | | | | | ●
| 4 | | | | | | | | | | ●
2 | 1 | ● | | | | | | | | ● | ●
| 2 | | | | | | | | | | ● | | | | | | | | | | ●
| 3 | ● | | | | | | | | ● | ●
| 4 | | | | | ● | | | | | ●
3 | 1 | | | | | ● | | | | | ●
| 2 | | | | | ● | | | | ● | ●
| 3 | ● | | | | | | | | | ●
| 4 | ● | | | | | | | | | ●
| 5 | | | | | | | | | ● | ●
| 6 | | | | | | | | | | ●
4 | 1 | ● | | | | | | | | | | | | | | | ●
| 2 | | | | | | | | | | | | | | | | ● | | 3 | 1
| 3 | | | | | | | | | | | | | | | | ● | | 1
| 4 | | | | | | | | | | | | ● | | | | | | 1
| 5 | ● | | | | | | | | ● | ● | ●
5 | 1a | | | | | | | | | | | ● | | | | | | | | | | | 1-2
| 1b | | | | | | | | | | | ● | | | | | | | | | | | 1-2
| 1c | | | | | | | | | | | ● | | | | | | | | | | | 2-3
| 1d | | | | | | | | | | | ● | | | | | | | | | | | 2-3
| 2 | | | | | | | | | | | | | | | ● | | | | | | | | 3
| 3 | | | | | | | | | | | | | | | ● | | | | | | | | 3
| 4 | | | | | | | | | | | | | | | ● | | | | | | | | 3
| 5 | | | | | | | | | | | | | | | ● | | | | | | | | 3
| 6
| 7 | | | | | | | | | | | | | | | ● | | ● | | | | | | 3
6 | 1 | | | | | | | | | | | | | | ● | ● | ● | ● | | | | | 1-2
| 2 | | all | 1 | 2-3 | | ● | ● | | | | ●
| 3 | | all | 1 | 2-3 | | ● | ● | | | | | | | | | | | | | | | | 1
7 | 1 | | all | 2 | 1-2 | | | | | | | | | | | | | | | | | | | | 2
| 2 | | all | 2 | 1-2 | | | | | | | | | | | | | | | | | | | | 2
| 3 | | all | 2 | 1-2
8 | 1 | | | | | | | | | | | | | | ●
9 | 1 | | | | | | | | | | | | | | | | | ●
| 2 | | | | | | | | | | | | | | | ● | | | | | | | 1-2
| 3 | | | | | | | | | | | | | | | | | | | | | 2-3

Baseline and mid-range PIC training and dev board operation guide | Page 20
Table A-7a: Enhanced mid-range assembler (lessons 1 - 10) GP/RA³ pull-up | segment A⁻D,F,G | segment E | digit 1 cathode | GP/RA² pull-up | RC5 → digit 1 | RA⁵ → digit 2 | RC0 → digit 3 | GP/RA⁰ LED | GP/RA¹ LED | GP/RA² LED | GP/RA⁴ LED | GP/RA⁵ LED

RC0 LED

RC1 LED

RC2 LED

RC3 LED

Clock source

Crystal

32 kHz → T0CKI

Piezo

AN0 source

LDR2

Var Freq (digital)

Var Freq (analog)

Lesson | Example | 3 | 4 | 5 | 6 | 7 | 8 | 9 | 10 | 11 | 12 | 13 | 14 | 15 | 16 | 17 | 18 | 19 | 20 | 21 | 22 | 23 | 24 | 25 | 26 | 27
1 | 1 | | | | | | | | | | ●
2 | 1 | | | | | | | | | | ●
3 | 1 | | | | | | | | | | ●
| 2 | | | | | | | | | | ●
4 | 1 | ● | | | | | | | | | ●
| 2 | ● | | | | | | | | | ●
| 3 | | | | | | | | | | ●
5 | 1 | ● | | | | | | | | ● | ●
| 2 | ● | | | | | | | | ● | ●
| 3 | ● | | | | | | | | | ●
| 4 | | | | | | | | | | ● | | | | | | | | | | ●
6 | 1 | | | | | | | | | | ●
| 2 | ● | | | | | | | | ● | ●
| 3 | | | | | | | | | | ● | | | | | | | | | | ●
| 4 | ● | | | | | | | | | ●
| 5 | ● | | | | ● | | | | ● | ●
| 6 | | | | | | | | | | ●
| 7a | ● | | | | | | | | | ●
| 7b | | | | | | | | | | ●
7 | 1 | | | | | | | | | ●
| 2 | ● | | | | | | | | ● | ●
| 3 | ● | | | | | | | | | ●
| 4 | ● | | | | | | | | ● | ●
| 5 | | | | | ● | | | | | ●
| 6 | | | | | ● | | | | ● | ●
8 | 1 | | | | | ● | | | | | ●
| 2 | | | | | ● | | | | ● | ●
| 3 | ● | | | | | | | | | ●
| 4 | ● | | | | | | | | | ●
| 5 | | | | | | | | | ● | ●
| 6 | | | | | | | | | | ●
9 | 1 | ● | | | | | | | | | | | | | | | ●
| 2 | | | | | | | | | | | | | | | | ● | | 4
| 3 | | | | | | | | | | | | | | | | ● | | 2 | 2
| 4 | | | | | | | | | | | | | | | | ● | | 3 | 1
| 5 | | | | | | | | | | | | | | | | ● | | 1
| 6 | | | | | | | | | | | | ● | | | | | | 1
| 7 | ● | | | | | | | | ● | ● | ●
10 | 1a | | | | | | | | | | | ● | | | | | | | | | | | 1-2
| 1b | | | | | | | | | | | ● | | | | | | | | | | | 1-2
| 1c | | | | | | | | | | | ● | | | | | | | | | | | 2-3
| 1d | | | | | | | | | | | ● | | | | | | | | | | | 2-3
| 2 | | | | | | | | | | | | | | | ● | | | | | | | | 3
| 3 | | | | | | | | | | | | | | | ● | | | | | | | | 3
| 4 | | | | | | | | | | | | | | | ● | | | | | | | | 3

Baseline and mid-range PIC training and dev board operation guide | Page 21
Table A-7b: Enhanced mid-range assembler (lessons 11 - 18) GP/RA³ pull-up | segment A⁻D,F,G | segment E | digit 1 cathode | GP/RA² pull-up | RC5 → digit 1 | RA⁵ → digit 2 | RC0 → digit 3 | GP/RA⁰ LED | GP/RA¹ LED | GP/RA² LED | GP/RA⁴ LED | GP/RA⁵ LED

RC0 LED

RC1 LED

RC2 LED

RC3 LED

Clock source

Crystal

32 kHz → T0CKI

Piezo

AN0 source

LDR2

Var Freq (digital)

Var Freq (analog)

Lesson | Example | 3 | 4 | 5 | 6 | 7 | 8 | 9 | 10 | 11 | 12 | 13 | 14 | 15 | 16 | 17 | 18 | 19 | 20 | 21 | 22 | 23 | 24 | 25 | 26 | 27
11 | 1 | | | | | | | | | | | | | | | ● | | | | | | | | 3
| 2
| 3 | | | | | | | | | | | | | | | ● | | ● | | | | | | 3
| 4 | | | | | | | | | | | | | | | ● | | ● | | | | | | 3
12 | 1 | | all | 1 | 1-2
| 2 | | all | 1 | 2-3 | | ● | ● | ●
| 3 | | all | 1 | 2-3 | | ● | ● | ●
13 | 1 | | | | | | | | | | | | | | ● | ● | ● | ● | | | | | 1-2
| 2 | | | | | | | | | | | | | | ● | ● | ● | ● | | | | | 1-2
| 3 | | all | 1 | 2-3 | | ● | ● | ● | | | | | | | | | | | | | | | 1
| 4 | | all | 1 | 2-3 | | ● | ● | ● | | | | | | | | | | | | | | | 1
| 5 | | all | 1 | 2-3 | | ● | ● | | | | ●
14 | 1 | | all | 1 | 2-3 | | ● | ● | | | | | | | | | | | | | | | | 1
| 2 | | all | 1 | 2-3 | | ● | ● | | | | | | | | | | | | | | | | 1
| 3 | | all | 1 | 2-3 | | ● | ● | | | | | | | | | | | | | | | | 1
15 | 1 | ● | | | | | | | | ● | ●
| 2 | ● | | | | | | | | ● | ●
| 3 | | | | | | | | | | ● | | | | | | | | 4
| 4 | | | | | | | | | | ● | | | | | | | | 2 | 2
| 5 | ● | all | 2 | 1-2 | | | | | | | | | | | | | | 2 | 2
| 6 | ● | all | 2 | 1-2 | | | | | | | | | | | | | | 2 | 2
| 7 | | all | 2 | 1-2 | | | | | | | | | | | | | | | | | | | | 2
| 8 | | all | 2 | 1-2 | | | | | | | | | | | | | | | | | | | | 2
| 9 | | all | 2 | 1-2
16 | 1 | | | | | | | | | | | | | | ●
17 | 1 | | all | 2 | 1-2 | | | | | | | | | | | | | | | | | | | | 1
| 2 | | all | 2 | 1-2 | | | | | | | | | | | | | | | | | | | | 1
| 3 | | all | 2 | 1-2 | | | | | | | | | | | | | | | | | | | | 1
| 4 | | | | | | | | | | | | | | | | | ●
| 5 | | | | | | | | | | | | | | ●
| 6 | | | | | | | | | | | | | | ●
| 7 | | all | 1 | 2-3 | | ● | ● | | | | | | | | | | | | | | | | 1
18 | 1
| 2 | | | | | | | | | | | | | | | ● | | | | | | | 1-2
| 3 | | | | | | | | | | | | | | | | | | | | | | 1-2
| 4 | | | | | | | | | | | | | | | | | | | | | 1-2 | 1-2
| 5 | | | | | | | | | | | | | | | | | | | | | 2-3
| 6 | | | | | | | | | | | | | | | | | | | | | | 1-2
| 7 | | | | | | | | | | | | | | | | | | | | | | 1-2
| 8 | | | | | | | | | | | | | | | | | | | | | | 1-2
| 9 | | | | | | | | | | | | | | | | | | | | | 2-3

Baseline and mid-range PIC training and dev board operation guide | Page 22
Table A-8a: Enhanced mid-range C (lessons 1 - 10) GP/RA³ pull-up | segment A⁻D,F,G | segment E | digit 1 cathode | GP/RA² pull-up | RC5 → digit 1 | RA⁵ → digit 2 | RC0 → digit 3 | GP/RA⁰ LED | GP/RA¹ LED

GP/RA2 LED

GP/RA4 LED

GP/RA5 LED
RC0 LED

RC1 LED

RC2 LED

RC3 LED

Clock source

Crystal

32 kHz → T0CKI

Piezo

AN0 source

LDR2

Var Freq (digital)

Var Freq (analog)

Lesson | Example | 3 | 4 | 5 | 6 | 7 | 8 | 9 | 10 | 11 | 12 | 13 | 14 | 15 | 16 | 17 | 18 | 19 | 20 | 21 | 22 | 23 | 24 | 25 | 26 | 27
1 | 1 | | | | | | | | | | ●
2 | 1 | | | | | | | | | | ●
3 | 1 | ● | | | | | | | | | ●
| 2 | ● | | | | | | | | | ●
| 3 | | | | | | | | | | ●
4 | 1 | ● | | | | | | | | ● | ●
| 2 | ● | | | | | | | | ● | ●
| 3 | ● | | | | | | | | | ●
| 4 | | | | | | | | | | ● | | | | | | | | | | ●
5 | 1 | | | | | | | | | ●
| 2 | ● | | | | | | | | ● | ●
| 3 | ● | | | | | | | | | ●
| 4 | ● | | | | | | | | ● | ●
| 5 | | | | | ● | | | | | ●
| 6 | | | | | ● | | | | ● | ●
6 | 1 | | | | | ● | | | | | ●
| 2 | | | | | ● | | | | ● | ●
| 3 | ● | | | | | | | | | ●
| 4 | ● | | | | | | | | | ●
| 5 | | | | | | | | | ● | ●
| 6 | | | | | | | | | | ●
7 | 1 | ● | | | | | | | | | | | | | | | ●
| 2 | | | | | | | | | | | | | | | | ● | | 4
| 3 | | | | | | | | | | | | | | | | ● | | 2 | 2
| 4 | | | | | | | | | | | | | | | | ● | | 3 | 1
| 5 | | | | | | | | | | | | | | | | ● | | 1
| 6 | | | | | | | | | | | | ● | | | | | | 1
| 7 | ● | | | | | | | | ● | ● | ●
8 | 1a | | | | | | | | | | | ● | | | | | | | | | | | 1-2
| 1b | | | | | | | | | | | ● | | | | | | | | | | | 1-2
| 1c | | | | | | | | | | | ● | | | | | | | | | | | 2-3
| 1d | | | | | | | | | | | ● | | | | | | | | | | | 2-3
| 2 | | | | | | | | | | | | | | | ● | | | | | | | | 3
| 3 | | | | | | | | | | | | | | | ● | | | | | | | | 3
| 4 | | | | | | | | | | | | | | | ● | | | | | | | | 3
9 | 1 | | | | | | | | | | | | | | | ● | | | | | | | | 3
| 2
| 3 | | | | | | | | | | | | | | | ● | | ● | | | | | | 3
| 4 | | | | | | | | | | | | | | | ● | | ● | | | | | | 3
10 | 1 | | all | 1 | 1-2
| 2 | | all | 1 | 2-3 | | ● | ● | ●

Baseline and mid-range PIC training and dev board operation guide | Page 23

Table A-8b: Enhanced mid-range C (lessons 11 - 15)

GP/RA3 pull-up

segment A-D,F,G

segment E

digit 1 cathode

GP/RA2 pull-up
RC5 → digit 1

RA5 → digit 2
RC0 → digit 3
GP/RA0 LED

GP/RA1 LED

GP/RA2 LED

GP/RA4 LED

GP/RA5 LED
RC0 LED

RC1 LED

RC2 LED

RC3 LED

Clock source

Crystal

32 kHz → T0CKI

Piezo

AN0 source

LDR2

Var Freq (digital)

Var Freq (analog)

Lesson | Example | 3 | 4 | 5 | 6 | 7 | 8 | 9 | 10 | 11 | 12 | 13 | 14 | 15 | 16 | 17 | 18 | 19 | 20 | 21 | 22 | 23 | 24 | 25 | 26 | 27
11 | 1 | | | | | | | | | | | | | | ● | ● | ● | ● | | | | | 1-2
| 2 | | | | | | | | | | | | | | ● | ● | ● | ● | | | | | 1-2
| 3 | | all | 1 | 2-3 | | ● | ● | ● | | | | | | | | | | | | | | | 1
| 4 | | all | 1 | 2-3 | | ● | ● | ● | | | | | | | | | | | | | | | 1
| 5 | | all | 1 | 2-3 | | ● | ● | | | | ●
| 6 | | all | 1 | 2-3 | | ● | ● | | | | | | | | | | | | | | | | 1
| 7 | | all | 1 | 2-3 | | ● | ● | | | | | | | | | | | | | | | | 1
12 | 1 | ● | | | | | | | | ● | ●
| 2 | ● | | | | | | | | ● | ●
| 3 | | | | | | | | | | ● | | | | | | | | 4
| 4 | | | | | | | | | | ● | | | | | | | | 2 | 2
| 5 | ● | all | 2 | 1-2 | | | | | | | | | | | | | | 2 | 2
| 6 | ● | all | 2 | 1-2 | | | | | | | | | | | | | | 2 | 2
| 7 | | all | 2 | 1-2 | | | | | | | | | | | | | | | | | | | | 2
| 8 | | all | 2 | 1-2 | | | | | | | | | | | | | | | | | | | | 2
| 9 | | all | 2 | 1-2
13 | 1 | | | | | | | | | | | | | | ●
14 | 1 | | all | 2 | 1-2 | | | | | | | | | | | | | | | | | | | | 1
| 2 | | all | 2 | 1-2 | | | | | | | | | | | | | | | | | | | | 1
| 3 | | all | 2 | 1-2 | | | | | | | | | | | | | | | | | | | | 1
| 4 | | | | | | | | | | | | | | | | | ●
| 5 | | | | | | | | | | | | | | ●
| 6 | | | | | | | | | | | | | | ●
| 7 | | all | 1 | 2-3 | | ● | ● | | | | | | | | | | | | | | | | 1
15 | 1
| 2 | | | | | | | | | | | | | | | ● | | | | | | | 1-2
| 3 | | | | | | | | | | | | | | | | | | | | | | 1-2
| 4 | | | | | | | | | | | | | | | | | | | | | 1-2 | 1-2
| 5 | | | | | | | | | | | | | | | | | | | | | 2-3
| 6 | | | | | | | | | | | | | | | | | | | | | | 1-2
| 7 | | | | | | | | | | | | | | | | | | | | | | 1-2
| 8 | | | | | | | | | | | | | | | | | | | | | | 1-2
| 9 | | | | | | | | | | | | | | | | | | | | | 2-3

Baseline and mid-range PIC training and dev board operation guide | Page 24

### Appendix B – Parts list

PCB-mounted components

Qty | Description
4 | 22 pF ceramic capacitors
1 | 3.3 nF ceramic capacitor
1 | 10 nF ceramic capacitor
1 | 47 nF ceramic capacitor
1 | 82 nF ceramic capacitor
1 | 100 nF ceramic capacitor
16 | 330 Ω 5% 1/4W resistors
7 | 1 kΩ 5% 1/4W resistors
1 | 4.7 kΩ 5% 1/4W resistor
3 | 10 kΩ 5% 1/4W resistors
2 | 22 kΩ 5% 1/4W resistors
1 | 100 kΩ 5% 1/4W resistor
1 | 10 MΩ 5% 1/4W resistor
1 | 10 kΩ trimpot with thumbwheel (e.g. Bourns 3352T)
1 | 100 kΩ trimpot with thumbwheel (e.g. Bourns 3352T)
3 | BC337 NPN transistors (or BC547 / BC548 or similar)
1 | 1N400x series rectifier diode
2 | 32768 Hz “watch” crystal (12.5 pF load capacitance)
1 | 4.00 MHz ceramic resonator with built-in capacitor
3 | common-cathode 7-segment LED displays (10-pin DIP, e.g. Kingbright SC52-11SRWA)
1 | NE555 timer (bipolar)
1 | 74HCU04N hex inverter (unbuffered)
9 | 5 mm LEDs (red, green or yellow: normal intensity, diffused)
2 | CDS photocells (LDRs), 20-60 kΩ when illuminated

Baseline and mid-range PIC training and dev board operation guide | Page 25
1 | DC power jack (2.1 / 5.5 mm)
1 | 1 × 16-pin 0.1” pitch header socket
1 | 1 × 6-pin 0.1” pitch right-angle header
1 | 1 × 32-pin 0.1” snappable header (snap into 16 × 1×2 headers)
1 | 1 × 9-pin 0.1” snappable header (snap into 3 × 1×3 headers)
1 | 2 × 19-pin 0.1” snappable header (snap into 1 × 2×3, 1 × 2×4, 1 × 2×6, and 3 × 2×2 headers)
1 | 13 mm PCB ext drive piezo sounder (e.g. muRata PKM13EPYH4000)
1 | 8-pin DIP IC socket
1 | 14-pin DIP IC socket
2 | 6 mm PCB-mount tactile pushbutton switches

Accessories

Qty | Description
4 | self-adhesive rubber feet
1 | 2” × 3” solderless breadboard
| 22 AWG solid-core insulated jumper wire
20 | header shunts

Baseline and mid-range PIC training and dev board operation guide | Page 26

Additional components supplied for use with Gooligum baseline, mid-range and introductory enhanced mid-range PIC tutorials

Qty | Description
1 | PIC10F200-I/P MCU
1 | PIC12F509-I/P MCU
1 | PIC12F629-I/P MCU
1 | PIC12F1501-I/P MCU
1 | PIC16F506-I/P MCU
1 | PIC16F684-I/P MCU
1 | PIC16F1824-I/P MCU
1 | 1 nF ceramic capacitor
1 | 100 nF ceramic capacitor
2 | 1 µF ceramic capacitor
1 | 100 Ω 5% 1/4W resistor
1 | 1 kΩ 5% 1/4W resistor
1 | 4.7 kΩ 5% 1/4W resistor
2 | 6.8 kΩ 5% 1/4W resistor
2 | 10 kΩ 5% 1/4W resistors
2 | 22 kΩ 5% 1/4W resistors
2 | 100 kΩ 5% 1/4W resistors
2 | 1N4148 diodes
1 | 74HC14N hex Schmitt-trigger inverter
2 | CDS photocells (LDRs), 20-60 kΩ when illuminated
1 | PCB-mount pushbutton switch

Baseline and mid-range PIC training and dev board operation guide | Page 27

Additional components required for PWM lesson motor-control examples (optional)

Qty | Description
2 | PSMN022-30PL (or similar) N-channel logic level MOSFETs
2 | NDP6020P (or similar) P-channel logic level MOSFETs
1 | SN754410 (or L293D) quad half-H driver with internal clamp diodes
1 | MDN3BL3CSAS (or similar) 2 - 5 V brushed DC motor with wire leads
1 | 1N400x series rectifier diode
4 | 220 Ω 5% 1/4W resistors
2 | 10 kΩ 5% 1/4W resistors

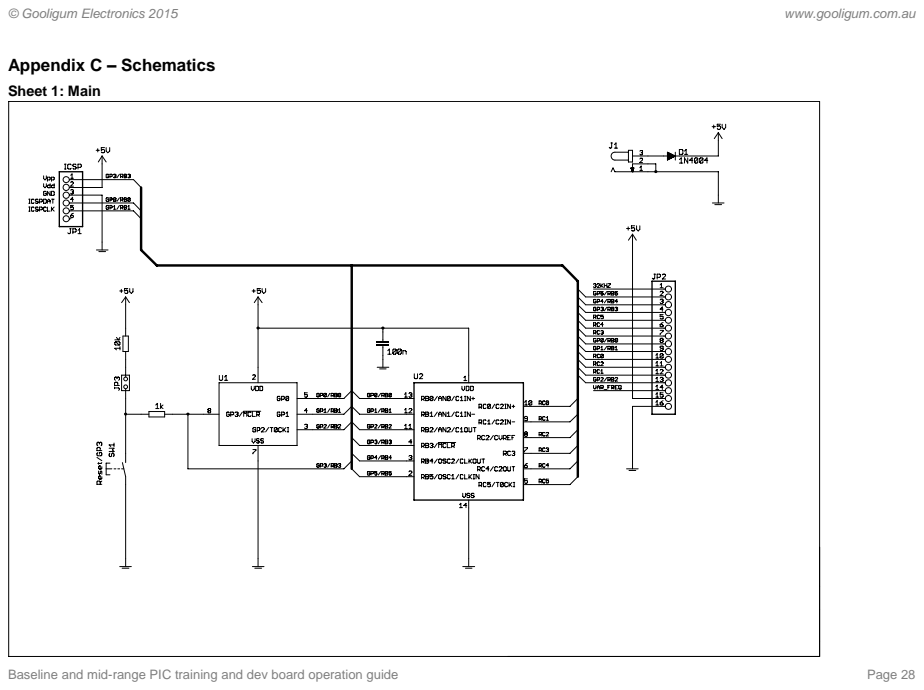
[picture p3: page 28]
Baseline and mid-range PIC training and dev board operation guide; Page 28; Appendix C – Schematics; Sheet 1: Main

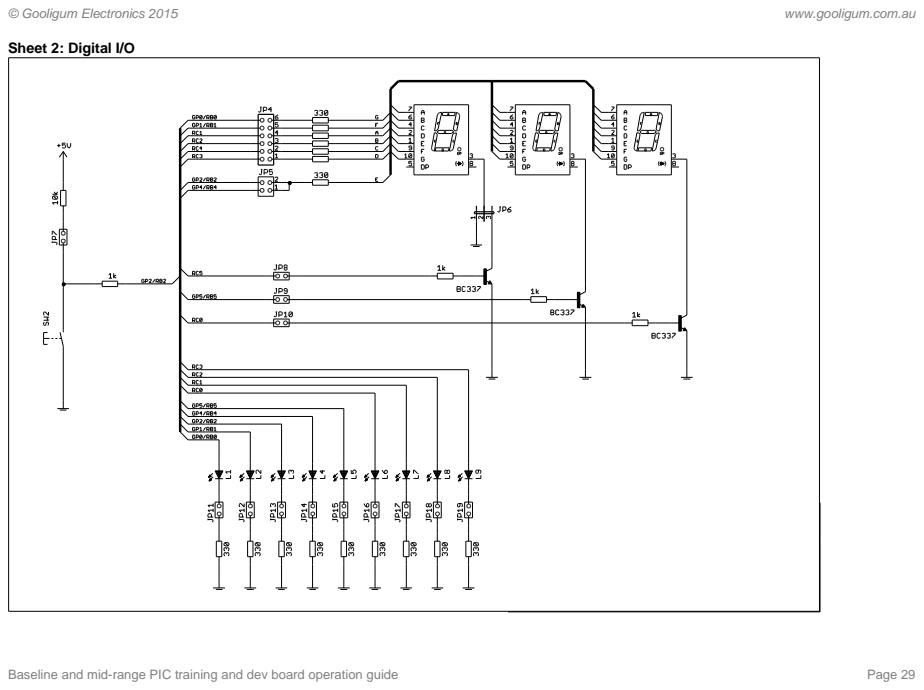
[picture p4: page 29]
Baseline and mid-range PIC training and dev board operation guide; Page 29; Sheet 2: Digital I/O

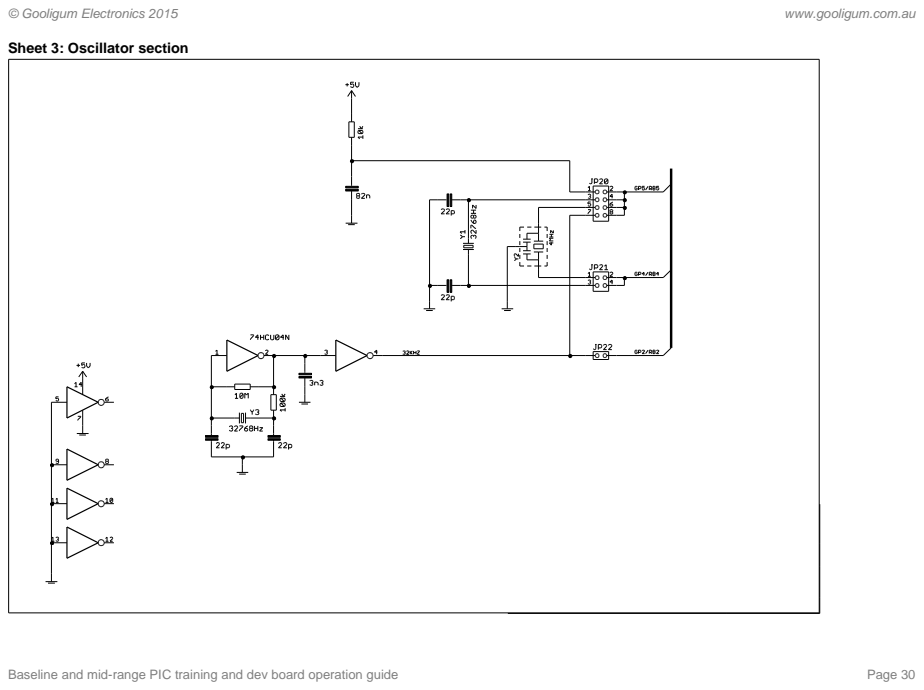
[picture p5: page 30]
Baseline and mid-range PIC training and dev board operation guide; Page 30

Sheet 3: Oscillator section

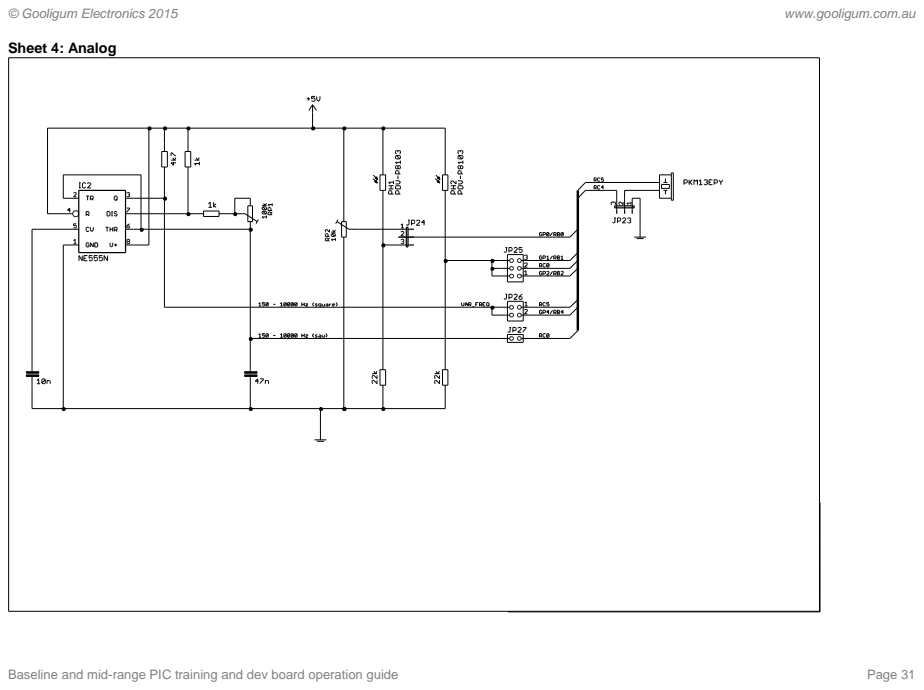
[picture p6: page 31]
Baseline and mid-range PIC training and dev board operation guide; Page 31; Sheet 4: Analog

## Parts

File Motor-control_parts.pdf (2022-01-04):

© Gooligum Electronics 2014 | www.gooligum.com.au
Baseline (6 – 14 pin) training and development board parts list | Page 1

### Motor Control Kit for Baseline Training and Development Board Parts List

Additional components required for PWM lesson motor-control examples (optional)

Qty | Description
2 | PSMN022-30PL (or similar) N-channel logic level MOSFETs
2 | NDP6020P (or similar) P-channel logic level MOSFETs
1 | SN754410 (or L293D) quad half-H driver with internal clamp diodes
1 | MDN3BL3CSAS (or similar) 2 V brushed DC motor with wire leads
1 | 1N400x series rectifier diode
4 | 220 Ω 5% 1/4W resistors
2 | 10 kΩ 5% 1/4W resistors

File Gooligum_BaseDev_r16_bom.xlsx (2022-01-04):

Gooligum Baseline PIC development board
Bill of Materials |  | rev 1.6 | 2013-07-23
Qty | Ref | Description | Value | Package | Manufacturer | Mfg Part# | Distributor | Dist Part# | Type | Side
1 | C1 | Capacitor: Ceramic 50V -20%,+80% | 100n | 5mm pitch radial | Murata | RDEF51H104Z0K1C03B | Digikey | 490-5401-ND | Thru-hole | Top
1 | C2 | Capacitor: Film 50V +/-5% | 82n | 5mm pitch radial | Panasonic - ECG | ECQ-V1H823JL | Digikey | P4524-ND | Thru-hole | Top
4 | C3,C4,C6,C7 | Capacitor: Ceramic 50V +/-5% | 22p | 0.1" pitch radial | Kemet | C315C220J2G5TA | Digikey | 399-4162-ND | Thru-hole | Top
1 | C5 | Capacitor: Film 50V +/-5% | 3n3 | 5mm pitch radial | Kemet | R82EC1330AA50J | Digikey | 399-6034-ND | Thru-hole | Top
1 | C8 | Capacitor: Ceramic 50V +/-10% | 10n | 2.5mm pitch radial | Murata | RPER71H103K2P1A03B | Digikey | 490-3812-ND | Thru-hole | Top
1 | C9 | Capacitor: Ceramic 50V +/-10% | 47n | 2.5mm pitch radial | Vishay | K473K15X7RF5TL2 | Digikey | BC1082CT-ND | Thru-hole | Top
1 | D1 | Rectifier Diode 1A | 1N4004 (1N4007 is ok) | DO41 | Comchip | 1N4004-G | Digikey | 641-1311-1-ND | Thru-hole | Top
3 | DSP1,DSP2,DSP3 | 1-digit 7-segment LED, CC, 0.56" red | (any pin-compatible) | 10-pin DIP, 0.6" | Lite-On Inc | LSHD-5503 | Digikey | 160-1576-5-ND | Thru-hole | Top
1 | IC1 | Hex Inverter IC (unbuffered) | 74HCU04 | 14-pin DIP | Texas Instruments | SN74HCU04N | Digikey | 296-9820-5-ND | Thru-hole | Top
1 | IC2 | 555 Timer IC | 555 | 8-pin DIP | Texas Instruments | NE555P | Digikey | 296-1411-5-ND | Thru-hole | Top
1 | J1 | DC Power Jack w switch, 2.1mm / 5.5mm |  | Through hole, right angle | CUI Inc | PJ-102A | Digikey | CP-102A-ND | Thru-hole | Top
1 | JP1 | Single row right-angle 0.025" sq post header |  | 1x6 0.1" pitch R/A male header | Samtec Inc | TSW-150-08-T-S-RA | Digikey | SAM1051-50-ND | Thru-hole | Top
1 | JP2 | Single row 0.025" sq post socket |  | 1x16 0.1" pitch female header | Samtec Inc | SSW-116-01-T-S | Digikey | SAM1213-16-ND | Thru-hole | Top
16 | JP3,JP7-19,JP22,JP27 | Single row 0.025" sq post header |  | 1x2 0.1" pitch male header | Samtec Inc | TSW-150-07-T-S | Digikey | SAM1035-50-ND | Thru-hole | Top
1 | JP4 | Two row 0.025" sq post header |  | 2x6 0.1" pitch male header | Samtec Inc | TSW-150-07-T-D | Digikey | SAM1034-50-ND | Thru-hole | Top
3 | JP6,JP23-24 | Single row 0.025" sq post header |  | 1x3 0.1" pitch male header | Samtec Inc | TSW-150-07-T-S | Digikey | SAM1035-50-ND | Thru-hole | Top
1 | JP25 | Two row 0.025" sq post header |  | 2x3 0.1" pitch male header | Samtec Inc | TSW-150-07-T-D | Digikey | SAM1034-50-ND | Thru-hole | Top
1 | JP20 | Two row 0.025" sq post header |  | 2x4 0.1" pitch male header | Samtec Inc | TSW-150-07-T-D | Digikey | SAM1034-50-ND | Thru-hole | Top
3 | JP5,JP21,JP26 | Two row 0.025" sq post header |  | 2x2 0.1" pitch male header | Samtec Inc | TSW-150-07-T-D | Digikey | SAM1034-50-ND | Thru-hole | Top
1 | L1 | LED: 5mm round 20mcd diffused green | Green | 5mm radial (0.1" pitch) | Kingbright | WP7113GD | Digikey | 754-1263-ND | Thru-hole | Top
1 | L2 | LED: 5mm round 20mcd diffused yellow | Yellow | 5mm radial (0.1" pitch) | Kingbright | WP7113YD | Digikey | 754-1284-ND | Thru-hole | Top
7 | L3-9 | LED: 5mm round 5mcd diffused red | Red | 5mm radial (0.1" pitch) | Kingbright | WP7113LID | Digikey | 754-1266-ND | Thru-hole | Top
2 | PH1,PH2 | LDR: CDS photocell, max 60k @ 10 lux, min 500k @ dark | PDV-P8104 | 0.2" dia radial (3.4mm pitch) | Advanced Photonix | PDV-P8104 | Digikey | PDV-P8104-ND | Thru-hole | Top
3 | Q1-3 | Transistor: NPN, 100mA | BC547 (BC548 or BC337 is ok) | TO92 bent lead (0.1" pitch) | Fairchild | BC547BTA | Digikey | BC547BTACT-ND | Thru-hole | Top
3 | R1,R10,R24 | Resistor: 10k +/-5% | 10k | axial, 7mm max lead spacing | Stackpole | CFM14JT10K0 | Digikey | S10KQCT-ND | Thru-hole | Top
7 | R2,R11-14,R28,R29 | Resistor: 1k +/-5% | 1k | axial, 7mm max lead spacing | Stackpole | CFM14JT1K00 | Digikey | S1KQCT-ND | Thru-hole | Top
16 | R3-9,R15-23 | Resistor: 330Ω +/-5% | 330 | axial, 7mm max lead spacing | Stackpole | CFM14JT330R | Digikey | S330QCT-ND | Thru-hole | Top
1 | R25 | Resistor: 10M +/-5% | 10M | axial, 7mm max lead spacing | Stackpole | CF18JT10M0 | Digikey | CF18JT10M0CT-ND | Thru-hole | Top
1 | R26 | Resistor: 100k +/-5% | 100k | axial, 7mm max lead spacing | Stackpole | CFM14JT100K | Digikey | S100KQCT-ND | Thru-hole | Top
1 | R27 | Resistor: 4k7 +/-5% | 4k7 | axial, 7mm max lead spacing | Stackpole | CFM14JT4K70 | Digikey | S4.7KQCT-ND | Thru-hole | Top
2 | R30,R31 | Resistor: 22k +/-5% | 22k | axial, 7mm max lead spacing | Stackpole | CFM14JT22K0 | Digikey | S22KQCT-ND | Thru-hole | Top
1 | RP1 | Trimpot: top-adjust thumbwheel | 100k | Bourns 3352T | Bourns Inc. | 3352T-1-104LF | Digikey | 3352T-104LF-ND | Thru-hole | Top
1 | RP2 | Trimpot: top-adjust thumbwheel | 10k | Bourns 3352T | Bourns Inc. | 3352T-1-103LF | Digikey | 3352T-103LF-ND | Thru-hole | Top
1 | SP1 | Piezo sounder, 4kHz, external drive |  | 13mm round piezo, 5mm pitch | Murata | PKM13EPYH4000-A0 | Digikey | 490-4698-ND | Thru-hole | Top
2 | SW1,SW2 | Switch tactile pushbutton SPST-NO |  | Through hole, 6mm x 6mm | TE Connectivity | FSM4JH | Digikey | 450-1650-ND | Thru-hole | Top
1 | U1 | 8-pin DIP socket, gold contacts | (machined pin, not dual wipe) | 8-pin DIP, 0.3" row spacing | Mill-Max | 110-41-308-41-001000 | Digikey | ED90515-ND | Thru-hole | Top
1 | U2 | 14-pin DIP socket, gold contacts | (machined pin, not dual wipe) | 14-pin DIP, 0.3" row spacing | Mill-Max | 110-41-314-41-001000 | Digikey | ED90516-ND | Thru-hole | Top
2 | Y1,Y3 | Crystal: 32.768 kHz, 12.5 pF | 32768Hz | Radial, 2mm x 6mm | Abracon | CRYSTALTC26V | Digikey | 535-9032-ND | Thru-hole | Top
1 | Y2 | Ceramic resonator, built-in capacitor | 4MHz | Radial, 2.5mm pitch | Murata | CSTLS4M00G53-B0 | Digikey | 490-1208-ND | Thru-hole | Top
20 | none (DNS) | Shunt (female) | 1 x 2 | 0.1" pitch | Sullins | QPC02SXGN-RC | Digikey | S9337-ND | N/A
1 | (as marked on board) | Solderless breadboard: 2" x 3" |  | 2.13" x 3.3" | Twin Industries | TW-E40-510 | Digikey | 438-1109-ND | N/A | Top

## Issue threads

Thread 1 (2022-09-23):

Gerber files - I'm told "the drill is shifted from the main board"

saepien, 2022-09-23:
Can you possibly correct this and re-create the gerbers and drill files?

I would do it but I don't have Eagle (KiCad only).

Tried importing to KiCad but that didn't work either!

Thanks a bunch David.

Closed 2022-09-26.
